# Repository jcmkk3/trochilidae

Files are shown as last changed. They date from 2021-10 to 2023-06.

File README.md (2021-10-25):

# 🐦trochilidae
A from-scratch re-creation of the [Hummingbird keyboard](https://github.com/PJE66/hummingbird) using ergogen

**NOTE:** *These boards are still a work-in-progress. They are awaiting the last few adjustments before the final routing and slikscreens are added.*

## The Family
### Rufous
*Selasphorus rufus*
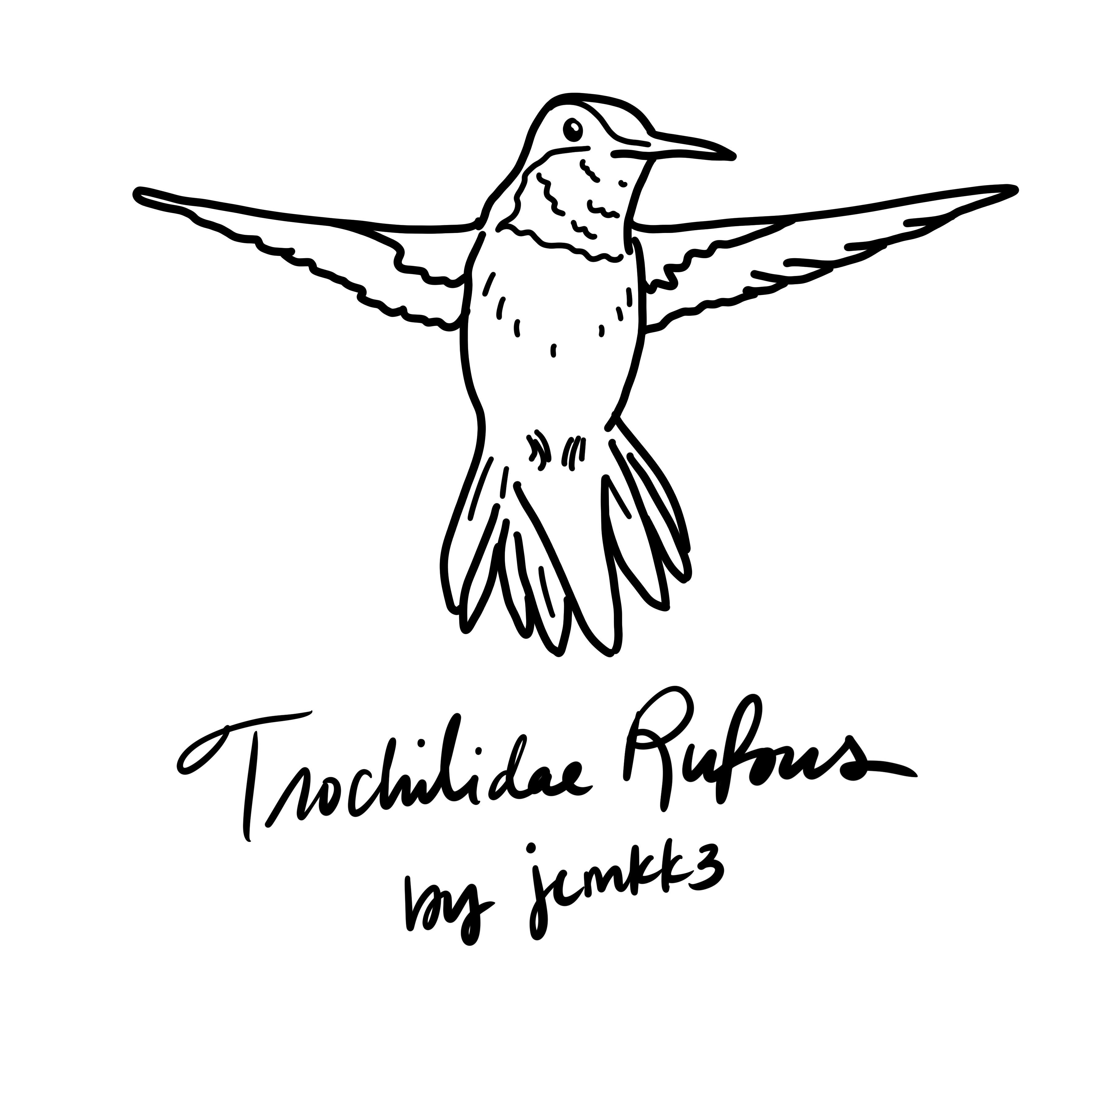
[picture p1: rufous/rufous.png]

This board is the basis of all other boards in this repo. It is modeled after the original hummingbird.

### Berylline
*Saucerottia beryllina*
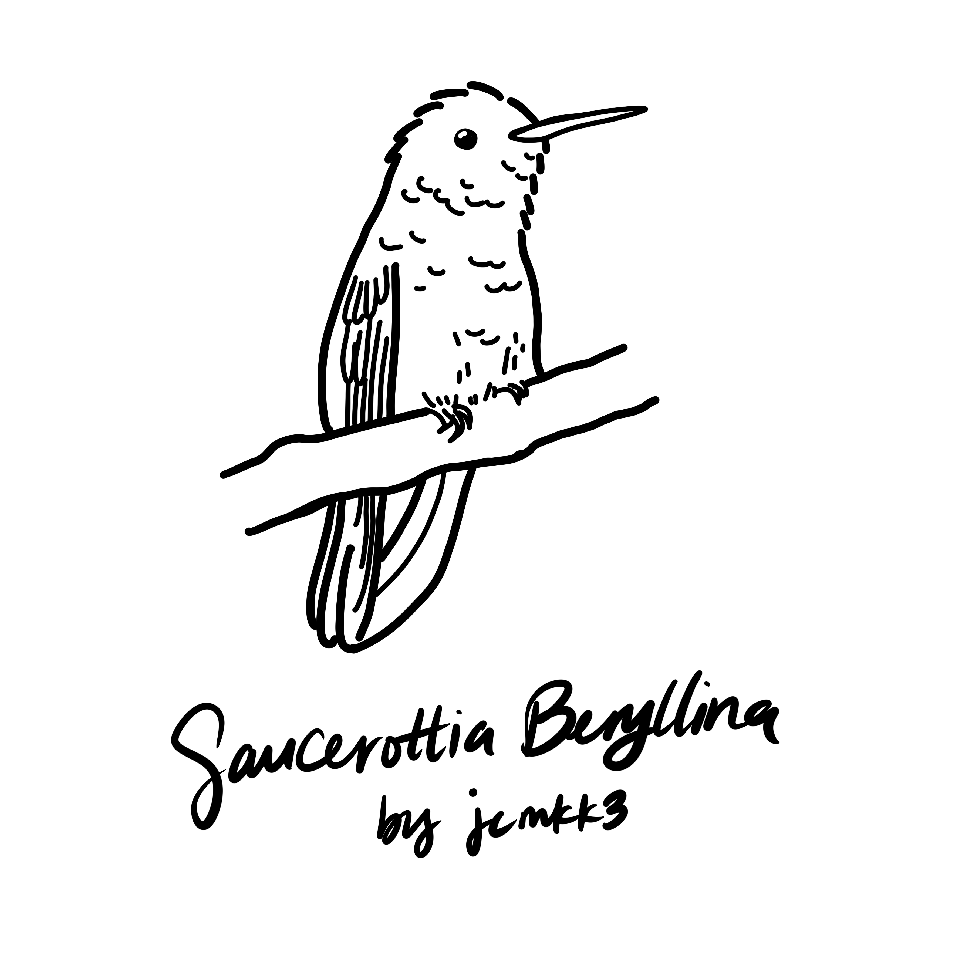
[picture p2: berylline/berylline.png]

This board features some adjustments to the key placement from the Rufous
- A slight increase in angle between the halves 23 -> 25 degrees
- 3 degrees of splay between pinky and ring columns
- 2 degrees of splay between ring and middle columns
- Slightly increased stagger for all columns
- Thumb keys are moved slightly towards the center

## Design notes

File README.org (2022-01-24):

#+title: 🐦trochilidae

A from-scratch re-creation of the [[https://github.com/PJE66/hummingbird][Hummingbird keyboard]] using ergogen

* The Family
** Rufous
/Selasphorus rufus/

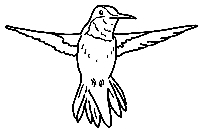
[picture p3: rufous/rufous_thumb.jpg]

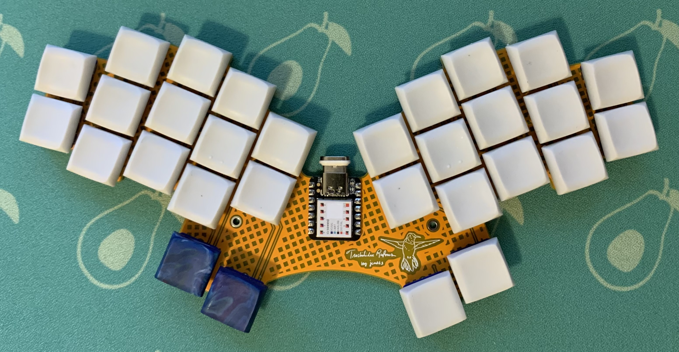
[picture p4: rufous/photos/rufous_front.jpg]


** Berylline
/Saucerottia beryllina/

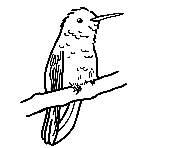
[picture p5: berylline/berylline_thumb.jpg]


*** Features
- Same key layout as my latest rufous splay unibody
- Meant for tented/puck usage
- MCU footprint to allow both controllers to be component side up
- Reset pads for easy tweezering
- Battery wire window in case you want to run the wires under the board (should be nice for builds with a case)
- A couple of holes for header pins meant to be used with a physical jumper to disconnect power if needed

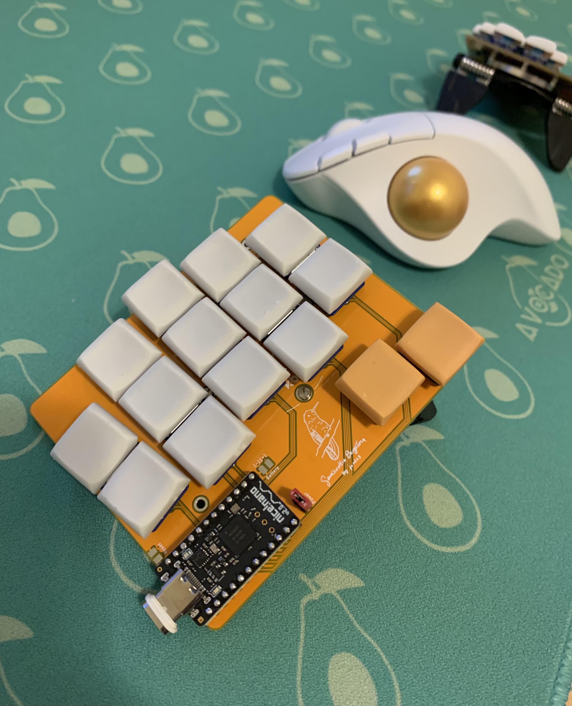
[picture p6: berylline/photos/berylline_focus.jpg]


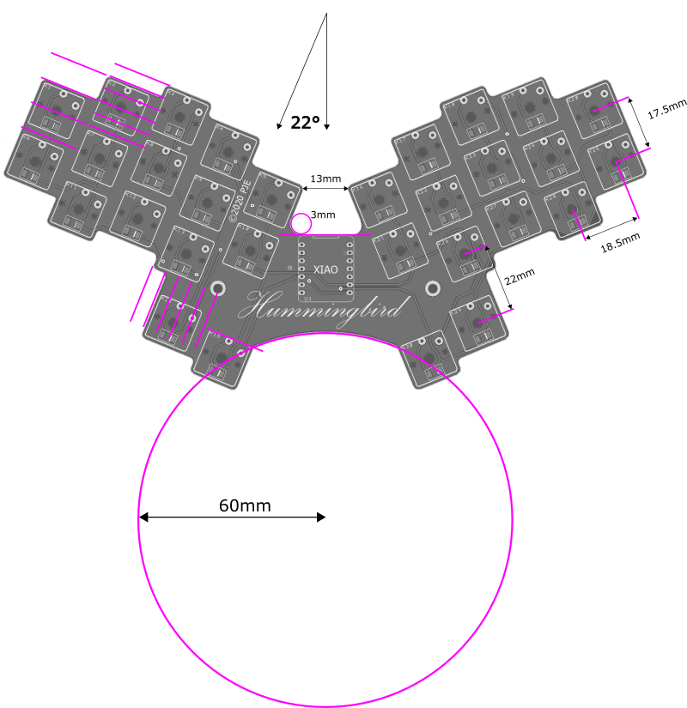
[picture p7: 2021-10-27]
hummingbird_anatomy.png

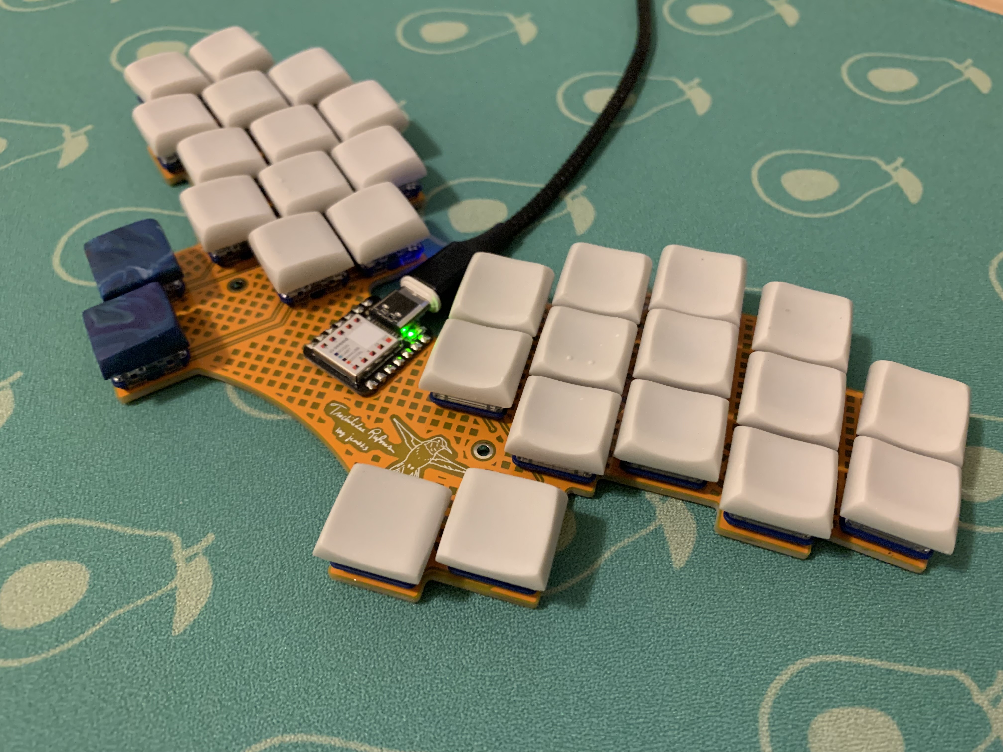
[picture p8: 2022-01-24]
rufous/photos/rufous_three_quarter.jpg

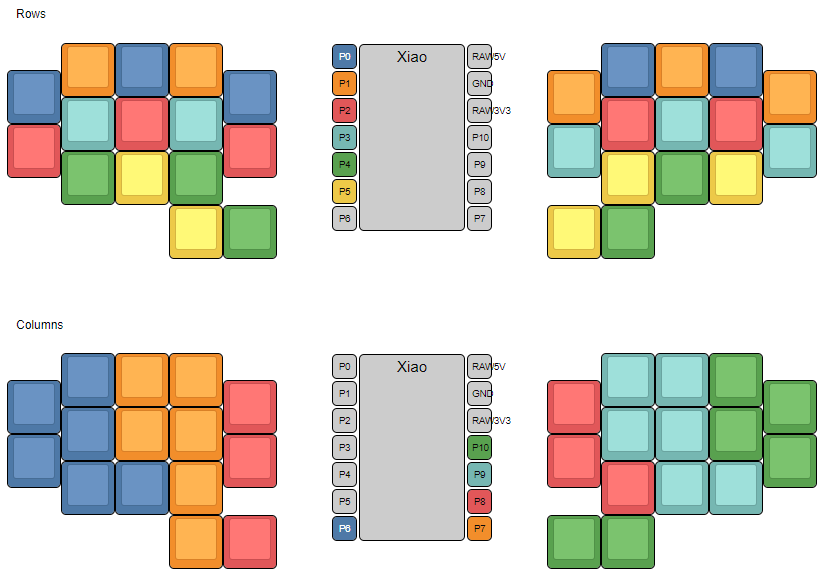
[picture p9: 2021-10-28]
key_matrix.png

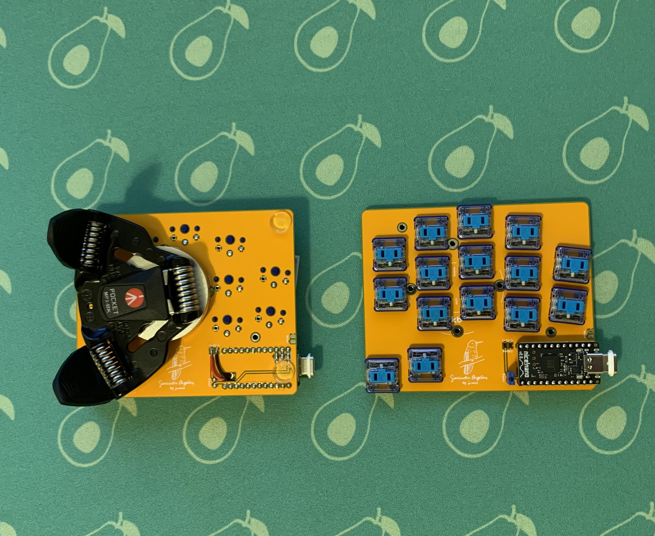
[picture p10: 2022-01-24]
berylline/photos/berylline_bottom.jpg

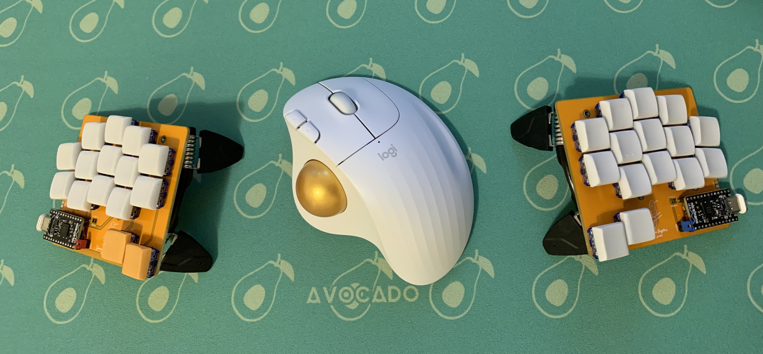
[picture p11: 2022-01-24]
berylline/photos/berylline_trackball.jpg

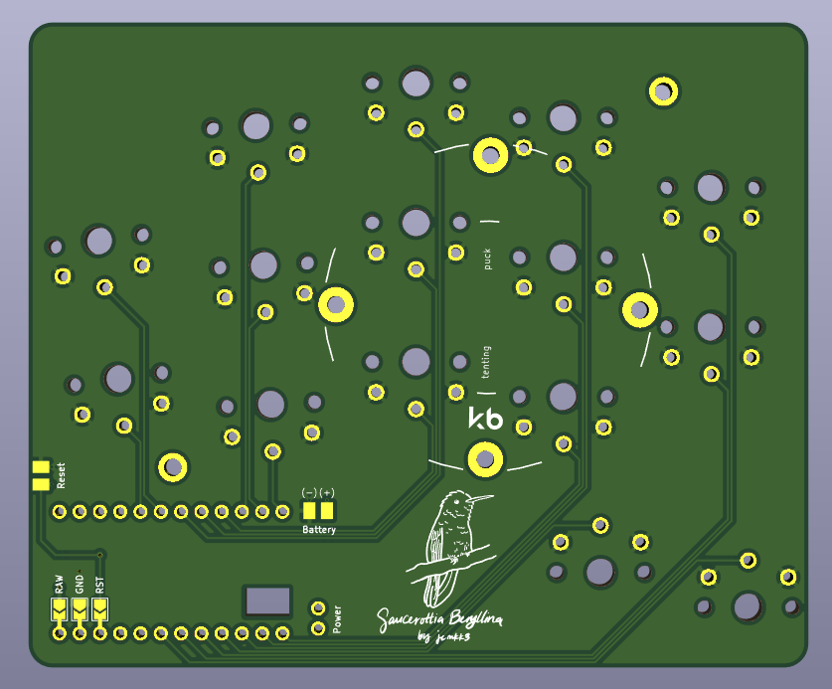
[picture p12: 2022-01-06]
berylline/berylline_pcb.png

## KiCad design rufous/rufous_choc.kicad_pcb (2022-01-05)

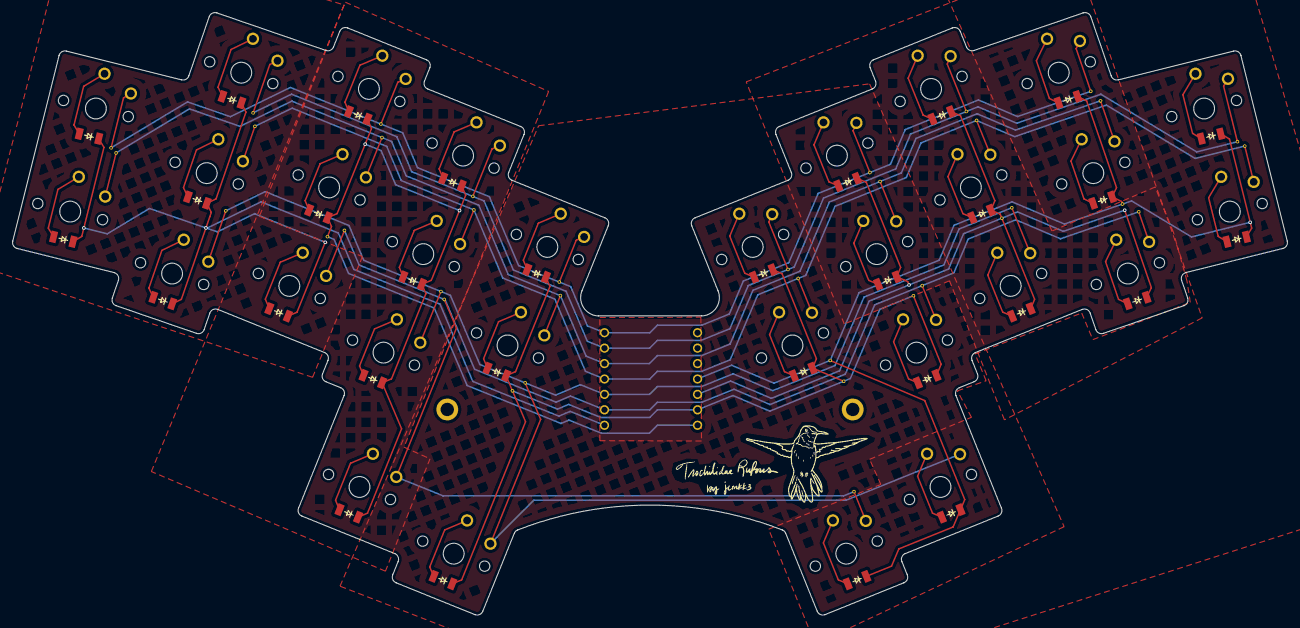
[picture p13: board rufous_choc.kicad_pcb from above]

Board: 2 copper layers, 210.0 x 99.2 mm, 62 parts (0 on the bottom side), 41 nets.

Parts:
D1, D2, D3, D4, D5, D6, D7, D8, D9, D10, D11, D12, D13, D14, D15, D16, D17, D18, D19, D20, D21, D22, D23, D24, D25, D26, D27, D28, D29, D30: BigDiode
HOLE1, HOLE2: M2MountingHoleSimple
S1, S2, S3, S4, S5, S6, S7, S8, S9, S10, S11, S12, S13, S14, S15, S16, S17, S18, S19, S20, S21, S22, S23, S24, S25, S26, S27, S28, S29, S30: PG1350

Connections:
P0: S2.1, S8.1, S13.1, S20.1, S26.1
P1: S5.1, S11.1, S17.1, S23.1, S28.1
P2: S1.1, S7.1, S12.1, S19.1, S25.1
P3: S4.1, S10.1, S16.1, S22.1, S27.1
P4: S3.1, S9.1, S15.1, S21.1, S29.1
P5: S6.1, S14.1, S18.1, S24.1, S30.1
P6: D1.1, D2.1, D3.1, D4.1, D5.1, D6.1
P7: D7.1, D8.1, D9.1, D10.1, D11.1, D14.1
P8: D12.1, D13.1, D15.1, D24.1, D27.1, D28.1
P9: D18.1, D21.1, D22.1, D23.1, D25.1, D26.1
P10: D16.1, D17.1, D19.1, D20.1, D29.1, D30.1
index_bottom: D9.2, S9.2
index_home: D10.2, S10.2
index_top: D11.2, S11.2
inner_home: D12.2, S12.2
inner_thumb: D15.2, S15.2
inner_top: D13.2, S13.2
middle_bottom: D6.2, S6.2
middle_home: D7.2, S7.2
middle_top: D8.2, S8.2
mirror_index_bottom: D24.2, S24.2
mirror_index_home: D25.2, S25.2
mirror_index_top: D26.2, S26.2
mirror_inner_home: D27.2, S27.2
mirror_inner_thumb: D30.2, S30.2
mirror_inner_top: D28.2, S28.2
mirror_middle_bottom: D21.2, S21.2
mirror_middle_home: D22.2, S22.2
mirror_middle_top: D23.2, S23.2
mirror_outer_thumb: D29.2, S29.2
mirror_pinky_home: D16.2, S16.2
mirror_pinky_top: D17.2, S17.2
mirror_ring_bottom: D18.2, S18.2
mirror_ring_home: D19.2, S19.2
mirror_ring_top: D20.2, S20.2
outer_thumb: D14.2, S14.2
pinky_home: D1.2, S1.2
pinky_top: D2.2, S2.2
ring_bottom: D3.2, S3.2
ring_home: D4.2, S4.2
ring_top: D5.2, S5.2

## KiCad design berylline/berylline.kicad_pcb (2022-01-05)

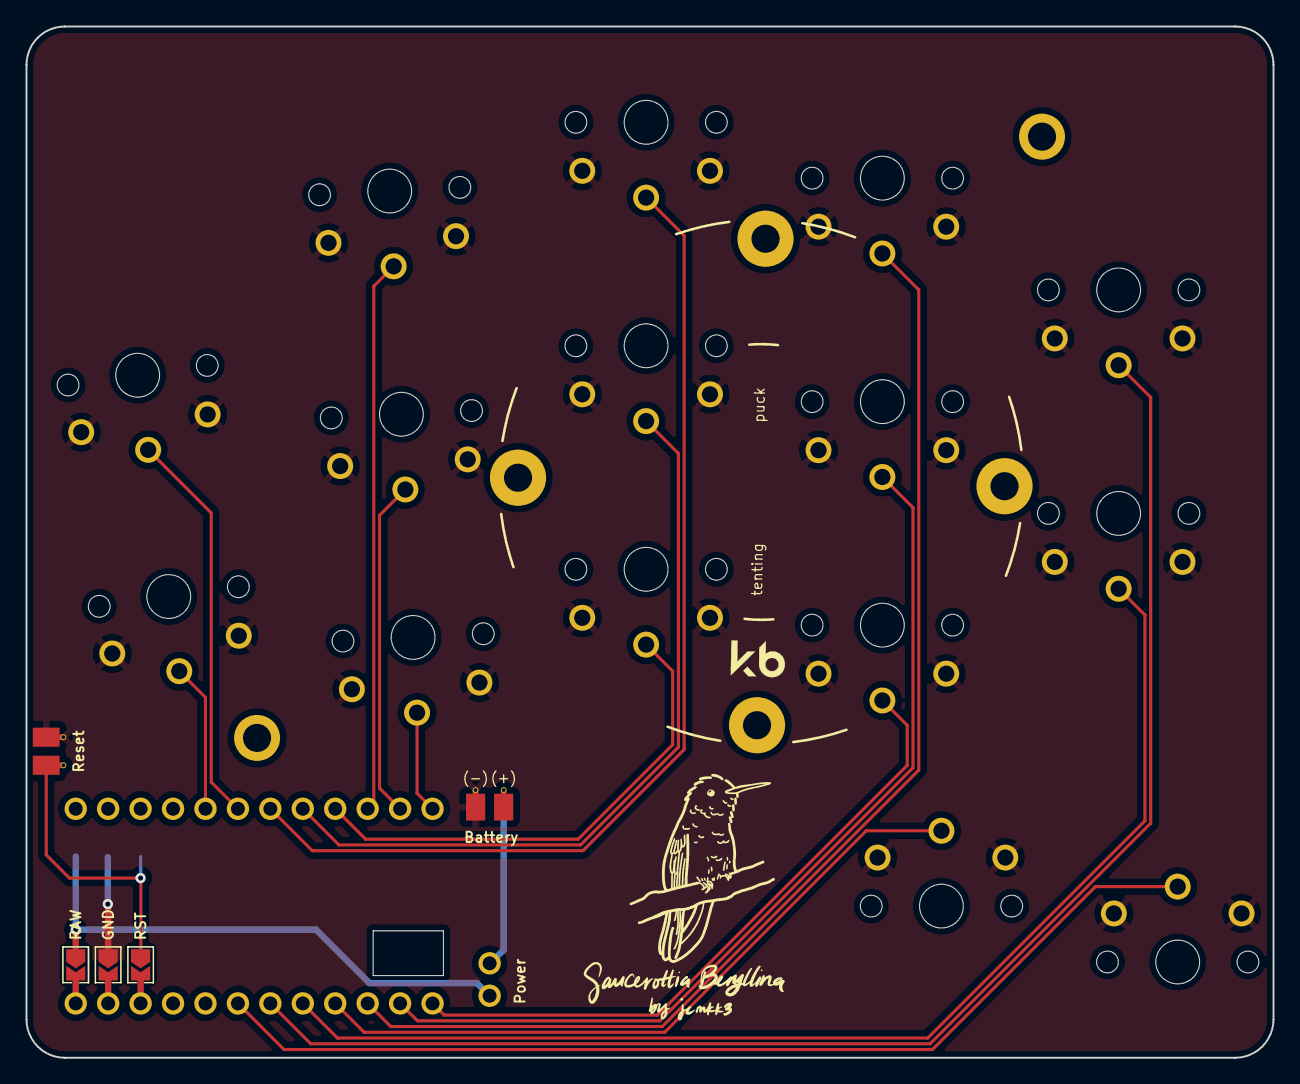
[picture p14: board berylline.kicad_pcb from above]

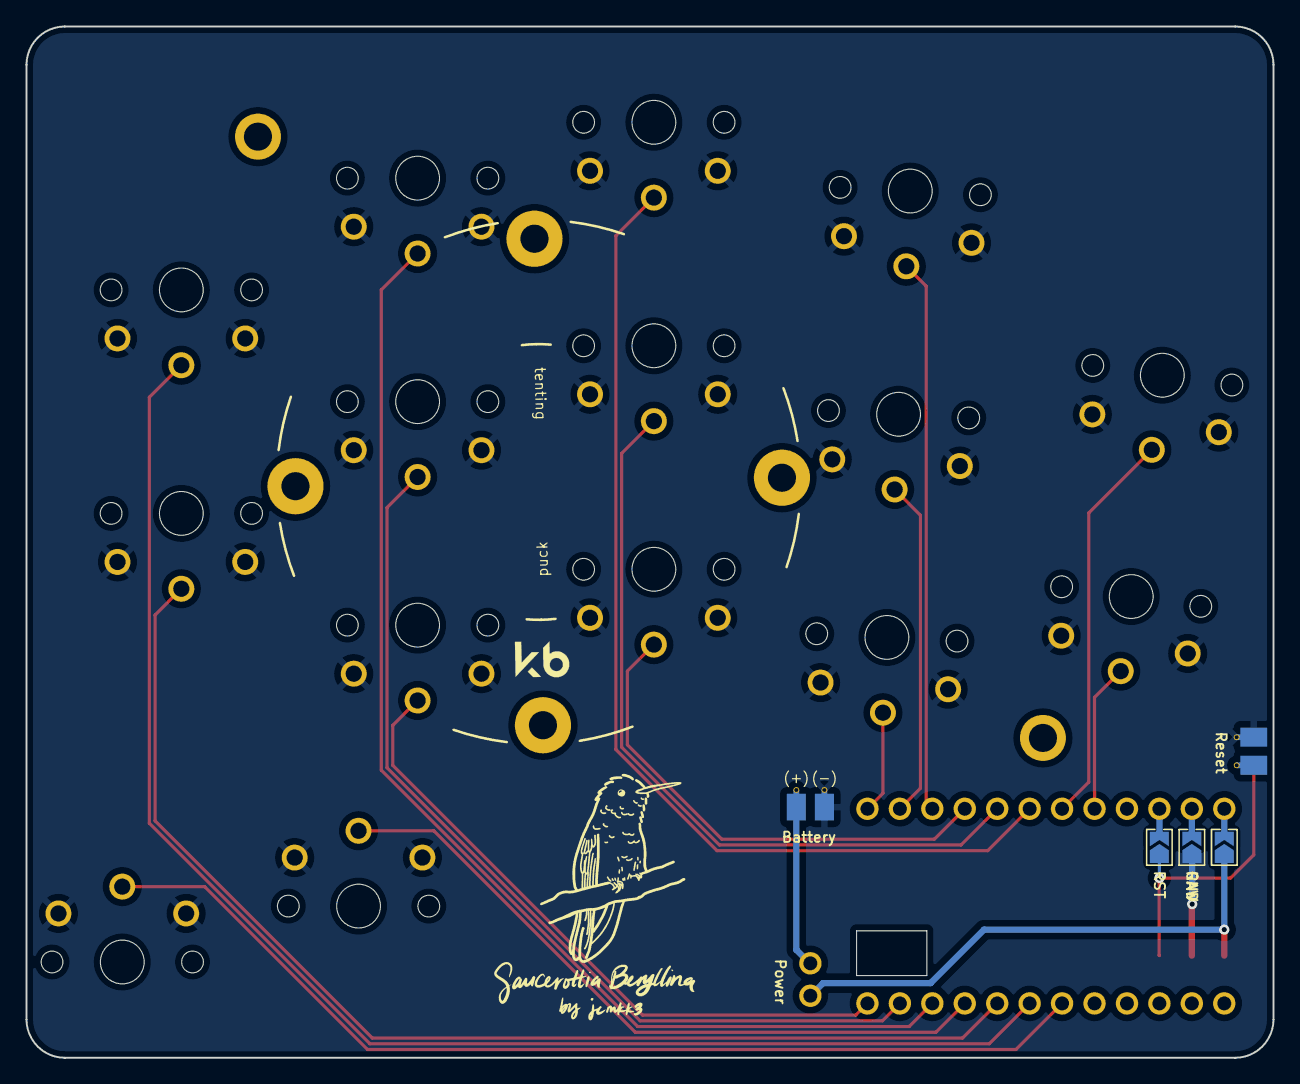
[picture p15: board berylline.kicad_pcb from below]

Board: 2 copper layers, 97.6 x 80.8 mm, 19 parts (3 on the bottom side), 18 nets.

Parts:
J1: Val**; HeaderJumperSimple
J2, J3: Battery_Cell; Battery_pads_reversible
MCU1: ProMicroSimpleJumper
S1, S2, S3, S4, S5, S6, S7, S8, S9, S10, S11, S12, S13, S14, S15: PG1350Reversible

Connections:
GND: J2.2, J3.2, MCU1.2, S1.1, S2.1, S3.1, S4.1, S5.1, S6.1, S7.1, S8.1, S9.1, S10.1, S11.1, S12.1, S13.1, S14.1, S15.1
P3: MCU1.18, S15.2
P4: MCU1.19, S13.2
P5: MCU1.20, S12.2
P6: MCU1.21, S14.2
P7: MCU1.22, S11.2
P8: MCU1.23, S10.2
P9: MCU1.24, S9.2
P10: MCU1.12, S3.2
P14: MCU1.10, S5.2
P15: MCU1.9, S6.2
P16: MCU1.11, S4.2
P18: MCU1.8, S7.2
P19: MCU1.7, S8.2
P20: MCU1.6, S2.2
P21: MCU1.5, S1.2
RAW: J1.1, J1.2, J2.1, MCU1.1
RST: J3.1, MCU1.3

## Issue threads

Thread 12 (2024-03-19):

Status of of xiao-berylline branch?

pupto-bismol, 2024-03-19:
Also just a question, not an issue:

I noticed the branch name here https://github.com/jcmkk3/trochilidae/tree/xiao-berylline and I am assuming that you plan to have a xiao BLE version of berylline at some point in the future - based off of the fact that I imported the berylline/berylline.kicad_pcb file into my own kicad and did not see the xiao footprint yet.

Do you have any estimate on when/how this will be done, or info on if you will add printable files to the releases page when finished? I'm quite interested in printing this board myself and would like to do so with xiao controllers instead of nice!nanos if possible.

I'm also quite interested in the design differences between the berylline v1 and the min-spaced version. Looking at the product page for the CS keycaps used in the original photos, they are said to be made for 17x18mm spacing, so the minimum spaced version would not fit those (and I was really hoping to get to try out those keycaps). Also curious on the reasoning for not keeping the tenting puck holes and adding a new splay angle between the index and middle columns - do you find the splay layout is more comfortable?

jcmkk3, 2024-03-24:
Hi @pupto-bismol,

I've toyed with the idea of a xiao based berylline before, but I don't know if I'll ever do it. The reason is that the xiao doesn't have a convenient built-in place for a battery like a nice!nano does. It also would make the build more complicated because it would require diodes.

I think that I originally made that repo with the intention of experimenting, but the real experiments were in a case design. I never changed anything with the pcb to support a xiao, but knew that if I was going to do that, I'd need a case to hold a battery. I kept it around as an example for myself on a simple case design.

The choc min-spaced version is meant for pseudoku's Philadelphia Minimalist (PM) keycaps instead of Chicago Steno (CS). There aren't any cast versions that you can buy from asymplex, unfortunately. You can only print them. The source files can be found in this repo: https://github.com/pseudoku/PseudoMakeMeKeyCapProfiles

Pseudoku did an export for me of 14.5 x 14.5 sized keycaps that are the perfect size for chocs. You can find those in the low profile keyboard discord https://discord.gg/xmQtdVRBKg
A direct link to the post: https://discord.com/channels/669011382284451861/831948386198093834/970866610095157309

The reason that the tenting puck holes went away is because there wasn't a good place to put the mounting holes for the puck that didn't interfere with the switches in the condensed spacing. The splay angles were tweaked to compensate for the overall key spacing being more narrow.

I'm going to close this issue, but feel free to ask more questions here if you'd like. You can also ask questions in my channel on the absolem keyboard server https://discord.gg/PaCpa2uX8B

pupto-bismol, 2024-03-26:
Thanks for the feedback! Right now I'm working in a local repo adding some of the modifications I want, including adapting berylline for a xiao BLE, adding two extra pinky keys, putting the spacing at standard choc 17x18, and possibly adding an encoder. When I'm done with everything would you want me to open a PR? I could open one with or without the extra pinky keys - stuff like the precise spacing of the splayed columns may not be the same still, though I kept the angles the same, and the edge cuts will probably not be the same as they were. But I would be happy to contribute if you'd like

jcmkk3, 2024-03-26:
It’s great to hear that you’re making it your own. No need to contribute back. One of my goals with these designs was to give a starting point that others could remix and extend to their own needs. It would be great if you published it to your own repo so that others could use/remix your design as well. I’d be happy to see the final result.

Closed 2024-03-24.

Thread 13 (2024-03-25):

type of power switch and reset button

ascodeasice, 2024-03-25:
Hi, I've been trying to build a berylline MX recently, and I wonder what type of power switch and reset button does it use

Closed 2024-04-16.

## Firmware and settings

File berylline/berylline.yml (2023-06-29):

meta:
  engine: 4.0.0
  name: berylline
  version: 0.4
  author: jcmkk3
  url: https://github.com/jcmkk3/trochilidae

presets:
  # These presets provide different layout options
  # Select a preset in the `units` section below
  # Note: The appropriate switch footprint will still need to be set in the `pcb` section
  choc_spaced:
    capx: 17        # Key cap size horizontal
    capy: 16        # Key cap size vertical
    kx: 18 + 0.5    # Key spacing horizontal
    ky: 17 + 0.5    # Key spacing vertical
    pinky_splay: 5  # Degrees of splay between pinky and ring columns
    pinky_adj: -3   # Adjustment to compensate for splay spacing
    ring_splay: 3
    ring_adj: -8
    middle_splay: 0
    middle_adj: 0
    thumb_offsetx: 0.25kx
  
  choc_min_spaced:
    capx: 14.5
    capy: 14.5
    kx: 15 + 0.5
    ky: 15 + 0.5
    pinky_splay: 5
    pinky_adj: -3
    ring_splay: 3
    ring_adj: -8
    middle_splay: 3
    middle_adj: -5
    thumb_offsetx: 1/3kx

  mx_spaced:
    capx: 18
    capy: 18
    kx: 19
    ky: 19
    pinky_splay: 5
    pinky_adj: -4
    ring_splay: 3
    ring_adj: -10
    middle_splay: 0
    middle_adj: 0
    thumb_offsetx: 0.25kx
  
  mx_min_spaced:
    capx: 15.5
    capy: 15.5
    kx: 16 + 0.5
    ky: 16 + 0.5
    pinky_splay: 5
    pinky_adj: -3
    ring_splay: 3
    ring_adj: -8
    middle_splay: 3
    middle_adj: -5
    thumb_offsetx: 1/3kx

units:
  $extends: presets.mx_spaced

  # Defaults/Constants
  # ==================
  $default_height: 0  # Points invisible by default unless height/width explicitly set
  $default_width: 0
  promicro_x: 33
  promicro_y: 18
  sf: 15


  pcb_thickness: 1.6
  plate_thickness: 1.2
  switch_pin_depth: 3 + 1
  plate_height: 2.2
  wall_thickness: 1
  keycap_bottom_height: 5
  case_overlap: 1

points:
  # Keys/Switches
  # =============
  zones.matrix:
    rotate: pinky_splay + ring_splay + middle_splay
    key:
      width: capx
      height: capy
      spread: kx      
      padding: ky
    rows:
      bottom:
      home:
      top:
    columns:
      pinky:
        rows:
          bottom.skip: true
          home.bind: [ky, kx, 0, kx]
          top.bind: [0, kx, ky, 0]
      ring:
        key:
          stagger: 2/3ky
          splay: -pinky_splay
          origin: [0, pinky_adj]
        rows:
          bottom.bind: [ky, 0, 0, 0]
          home.bind: [ky, 0, ky, 0]
          top.bind: [0, kx, ky, 0]
      middle:
        key:
          stagger: 0.25ky
          splay: -ring_splay
          origin: [0, ring_adj]
        rows:
          bottom.bind: [ky, kx, 0, kx]
          home.bind: [ky, 0, ky, 0]
          top.bind: [0, 0, ky, 0]
      index:
        key:
          stagger: -0.25ky
          splay: -middle_splay
          origin: [0, middle_adj]
        rows:
          bottom.bind: [ky, 0, 0, 0]
          home.bind: [ky, 0, ky, 0]
          top.bind: [0, 0, ky, kx]
      inner:
        key.stagger: -0.5ky
        rows:
          bottom.skip: true
          home.bind: [ky, 0, 0, kx]
          top.bind: [0, 0, ky, kx]
  zones.thumb:
    anchor:
      ref: matrix_index_bottom
      shift: [thumb_offsetx, -22]
    key.$extends: points.zones.matrix.key
    columns:
      tucky:
      reachy.key:
        stagger: -0.25ky
        bind: [0, 0, 0, kx]

  # Outline Extents
  # ===============
  zones.outline_top_left:
    anchor:
    - ref: matrix_middle_top
      shift: [0.5sf, 0.5sf]
      affect: y
    - ref: matrix_pinky_top
      affect: x
      shift: [-0.5sf, 0.5sf]
  zones.outline_top_right:
    anchor:
    - ref: outline_top_left
    - ref: thumb_reachy
      affect: x
      shift: [0.5sf, -0.5sf]
  zones.outline_bottom_left:
    anchor:
    - ref: outline_top_left
    - ref: thumb_reachy
      affect: y
      shift: [0.5sf, -0.5sf]
  zones.outline_bottom_right:
    anchor:
    - ref: outline_top_right
    - ref: outline_bottom_left
      affect: y

  # Components
  # ==========
  zones.mcu:
    anchor:
      ref: outline_bottom_left
      shift: [0.5promicro_x + 3, 0.5promicro_y + 3]
    key:
      width: promicro_x
      height: promicro_y
  zones.battery_connector:
    anchor:
      ref: matrix_index_bottom
      affect: xy
      shift: [-kx, -0.5ky]
    key:
      height: 1.5
      width: 6
  zones.reset:
    anchor:
      - ref: mcu
        shift: [0, 0.5promicro_y + 4]
        affect: y
      - ref: outline_bottom_left
        shift: [2.5, 0]
        affect: x
    key:
      height: 6
      width: 3
  zones.mounting_hole_top:
    anchor:
      - ref: matrix_pinky_top
        affect: y
        shift: [0, 0.5ky + 4.5]
      - ref: matrix_ring_top
        affect: x
        shift: [-0.5kx - 2.5, 0]
    key:
      height: 2
      width: 2
  zones.mounting_hole_bottom:
    anchor:
      - ref: matrix_inner_home
        affect: y
        shift: [0, -0.5ky - 2.5]
      - ref: matrix_index_bottom
        affect: x
        shift: [0.5kx + 2.5, 0]
    key.$extends: points.zones.mounting_hole_top.key
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

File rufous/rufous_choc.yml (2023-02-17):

units:
  # Parameters
  # ==========
  capx: cx        # Key cap size horizontal
  capy: cy        # Key cap size vertical
  kx: cx + 0.5    # Key spacing horizontal
  ky: cy + 0.5    # Key spacing vertical
  angle: 22       # Angle between halves
  pinky_stagger: 2/3ky
  pinky_splay: 5  # Degrees of splay between pinky and ring columns
  pinky_adj: -3   # Adjustment to compensate for splay spacing
  ring_splay: 3
  ring_adj: -8

  # Constants
  # =========
  xiao_x: 17.5
  xiao_y: 20
  visual_x: 1     # Visual representation of keycaps horizontal
  visual_y: 1     # Visual representation of keycaps vertical
  sf: 16          # Switch footprint (square)

points:
  zones.matrix:
    rotate: -angle + pinky_splay + ring_splay
    mirror: &mirror
      ref: matrix_inner_top
      shift: [0.5sf, 0.5sf]
      distance: 13
    key: &key
      width: capx
      height: capy
      autobind: false      
      tags:
        keys: true
      footprints:
      - type: choc
        nets:
          from: =row_net
          to: =column_net
        params:
          keycaps: true
    rows:
      bottom.padding: ky
      home.padding: ky
      top.padding: ky
    columns.pinky:
      key.spread: kx
      rows:
        bottom.skip: true
        home:
          bind: [0.5ky, 0.5kx, 0, 0]
          row_net: P2
          column_net: P6
        top:
          bind: [0, 0.5kx, 0.5ky, 0]
          row_net: P0
          column_net: P6
        home.mirror:
          row_net: P3
          column_net: P10
        top.mirror:
          row_net: P1
          column_net: P10
    columns.ring:
      key:
        spread: kx
        stagger: pinky_stagger
        splay: -pinky_splay
        origin: [0, pinky_adj]
      rows:
        bottom:
          bind: [0.5ky, 0, 0, 0]
          row_net: P4
          column_net: P6
        home:
          bind: [0, 0.5kx, 0, 0]
          row_net: P3
          column_net: P6
        top:
          bind: [0, 0.5kx, 0.5ky, 0]
          row_net: P1
          column_net: P6
        bottom.mirror:
          row_net: P5
          column_net: P9
        home.mirror:
          row_net: P2
          column_net: P10
        top.mirror:
          row_net: P0
          column_net: P10
    columns.middle:
      key:
        spread: kx
        stagger: 0.25ky
        splay: -ring_splay
        origin: [0, ring_adj]
      rows:
        bottom:
          bind: [0.5ky, 0.5kx, 0, 0.5kx]
          row_net: P5
          column_net: P6
        home:
          bind: [0, 0.5kx, 0, 0]
          row_net: P2
          column_net: P7
        top:
          bind: [0, 0, 0.5ky, 0]
          row_net: P0
          column_net: P7
        bottom.mirror:
          row_net: P4
          column_net: P9
        home.mirror:
          row_net: P3
          column_net: P9
        top.mirror:
          row_net: P1
          column_net: P9
    columns.index:
      key:
        spread: kx
        stagger: -0.25ky
      rows:
        bottom:
          bind: [0.5ky, 0, 0, 0]
          row_net: P4
          column_net: P7
        home:
          row_net: P3
          column_net: P7
        top:
          bind: [0, 0, 0.5ky, 0.5kx]
          row_net: P1
          column_net: P7
        bottom.mirror:
          row_net: P5
          column_net: P8
        home.mirror:
          row_net: P2
          column_net: P9
        top.mirror:
          row_net: P0
          column_net: P9
    columns.inner:
      key:
        spread: kx
        stagger: -0.5ky
      rows:
        bottom.skip: true
        home:
          bind: [0.5ky, 0, 0.5ky, 0.5kx]
          row_net: P2
          column_net: P8
          tags:
            matrix_inner: true
        top:
          bind: [0, 0, 0.5ky, 0.5kx]
          row_net: P0
          column_net: P8
          tags:
            matrix_inner: true
        home.mirror:
          row_net: P3
          column_net: P8
        top.mirror:
          row_net: P1
          column_net: P8
  zones.thumb:
    anchor:
      ref: matrix_index_bottom
      shift: [0.25kx, -22]
    mirror: *mirror
    key: *key
    columns:
      tucky:
        key:
          name: thumb_tucky
          bind: [0.5ky, 0.5kx, 0, 0]
          row_net: P5
          column_net: P7
        key.mirror:
          row_net: P4
          column_net: P10
      reachy:
        key:
          spread: kx
          stagger: -0.25ky        
          name: thumb_reachy
          bind: [1.5ky, 0, 0, 0]
          row_net: P4
          column_net: P8
        key.mirror:
          row_net: P5
          column_net: P10
  zones.mcu:
    anchor:
      aggregate.parts: [matrix_inner_top, mirror_matrix_inner_top]
      shift: [0, -0.7ky - 0.5xiao_y]
    key:
      name: mcu
      width: xiao_x
      height: xiao_y
      footprints:
      - type: xiao
        anchor:
          shift: [-0.5xiao_x, -0.5xiao_y]  # Anchor is topleft corner
  zones.mounting_hole:
    anchor:
      ref: matrix_inner_home
      shift: [-0.5kx + 4, -ky + 4]
    mirror: *mirror
    key:
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

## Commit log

2021-10-17 Fix top glue portion
2021-10-18 Change to single sided diodes in switch footprint
2021-10-19 Add switch plate
2021-10-19 Tweak switchplate
2021-10-20 Fix nets orientation on footprints
2021-10-21 Adjust switch footprint size
2021-10-21 Refactor center outline
    Remove the glue feature and use polygon instead for more control of positioning
2021-10-22 Adjust footprint spacing
2021-10-22 Adjust diode and thumb placement
2021-10-25 Fix diode direction
2021-10-25 Move footprint config at key level down near pcb section
2021-10-25 Slight adjustment to alignment caused by changing to glue
2021-10-25 Remove glue again
    Remove glue that was added in commit: 5ede06017c979f48422cca1b3838f6223ac0dc91
2021-10-26 Fix comment to remove glue reference
2021-10-26 Change pcb output name to match board name
2021-10-27 Add information about future boards
2021-10-28 Switch from diode footprint to 2 pads for more control
2021-10-28 Add mounting holes for case
2021-10-28 Back to regular diode footprint
2021-11-21 First attempt at a case
2021-11-21 Refine case
2021-11-21 Rearrange to keep PCB related items closer to each other
2021-11-22 Update footprint files
2022-01-02 Initial placement of reset, battery, and power
2022-01-04 Update/add footprints
2022-01-04 Add kicad file
    [berylline.kicad_pcb]
2022-01-04 Remove a couple of case mounts
    [berylline.kicad_pcb]
2022-01-05 Add kicad file in main repo
    [rufous_splay.kicad_pcb]
2022-01-05 Update pcb image
2022-01-05 Fix mcu silkscreen
2022-01-06 Reflect silkscreen fix
2022-01-24 Add photos of built boards
2022-02-23 Rufous cleanup and pre-release
    [rufous_choc.kicad_pcb, rufous_choc_hybrid.kicad_pcb, rufous_mx.kicad_pcb]
2022-02-24 Fix commented out lines
    [rufous_mx.yml]
2022-02-25 Change to promicro and current config structure
2022-02-25 First try at pin assignment
2022-03-13 Update footprints
2022-03-13 Correct net for thumbs
    [rufous_choc.yml, rufous_mx.yml]
2022-03-13 Update kicad files
    [rufous_choc_hybrid.kicad_pcb, rufous_mx.kicad_pcb]
2022-03-15 Add switchplates
2022-03-18 Clean up footprints
2022-04-25 Swap nets on reset and battery
2022-05-02 Formatting fixes to simple reviung
    [simple_reviung41.yml]
2022-05-13 Cleanups to berylline
    - Slightly adjust battery cutout
    - Improve reproducibility by removing some manual adjustments in kicad step
2022-05-13 Update footprints to latest
2022-06-03 Fix mounting hole placement
    [fancy_hummingbird.yml]
2022-06-05 Add pcb
2023-05-16 Berylline v4 update (#11)
    * Update berylline choc to v4
    * Add meta section
    * Increase spacing between switches and outline
    * Add presets section to consolidate spacing variations
2023-05-17 Add battery connector
2023-05-18 Swap nets on reset
    [berylline.yml]
2023-05-20 Update reset for optional switch
    [berylline.yml]
2023-06-22 Revert pinky spread limit
    [berylline.yml]
2023-06-22 Add MX preset and back to tight edgecuts
    [berylline.yml]
2023-06-27 First parts of case
2023-06-27 More complete case
